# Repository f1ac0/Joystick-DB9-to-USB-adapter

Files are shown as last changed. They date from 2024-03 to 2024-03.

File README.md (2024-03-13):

# Joystick DB9 to USB adapter
Connect an Atari/Amiga joystick or mouse to your PC using USB.

While plugging or powering up the adapter :
- leave all buttons disconnected to use a standard 1-3 buttons joystick or a CD32 pad (not really tested)
- press button 1 to control the PC mouse pointer using the joystick
- press button 2/right mouse button to use an Amiga mouse to control the PC pointer
- press both button 1 and 2/left and right mouse buttons to use an Atari mouse to control the PC pointer

# Disclaimer
This is a hobbyist project, it comes with no warranty and no support.

I publish my work under the CC-BY-NC-SA license.

If you find it useful and want to reward my hard work : I am always looking for Amiga/Atari/Amstrad/Commodore/Sinclair/Thomson... hardware to repair and hack, please contact me.

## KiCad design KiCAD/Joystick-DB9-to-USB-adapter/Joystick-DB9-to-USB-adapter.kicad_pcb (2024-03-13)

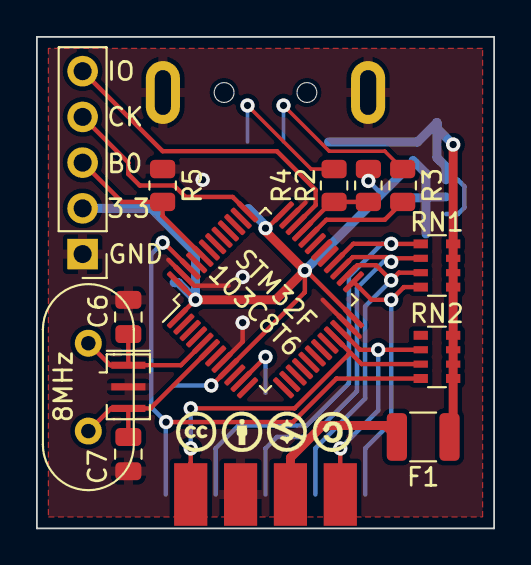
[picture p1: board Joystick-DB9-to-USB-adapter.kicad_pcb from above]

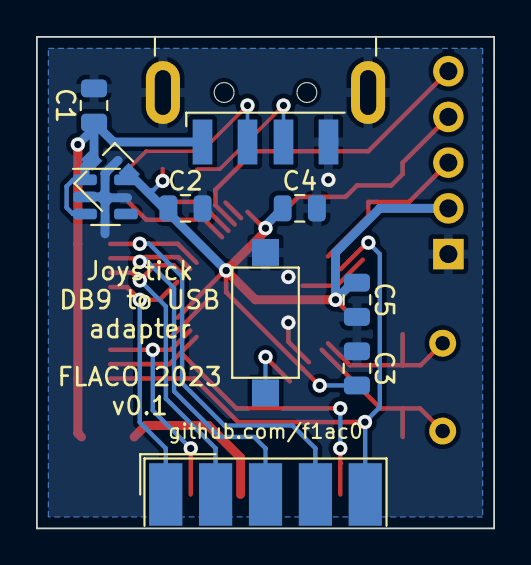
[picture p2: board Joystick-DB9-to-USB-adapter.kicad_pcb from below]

Board: 2 copper layers, 25.4 x 27.3 mm, 24 parts (10 on the bottom side), 21 nets.

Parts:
C1, C2: 1u; C_0805_2012Metric
C3, C4, C5: 100n; C_0805_2012Metric
C6, C7: 22p; C_0805_2012Metric
F1: Polyfuse 0.5A max; R_1210_3225Metric
FID1: License; CC_BY_NC_SA_long_silkscreen_11.4x3.5
J1: DE9_Receptacle; DSUB-9_Male_EdgeMount_P2.77mm
J2: USB_A; USB_A_CNCTech_1001-011-01101_Horizontal
J3: Prog; PinHeader_1x05_P2.54mm_Vertical
R2: 10k; R_0805_2012Metric
R3, R4: 22; R_0805_2012Metric
R5: 100k; R_0805_2012Metric
RN1, RN2: 10k; R_Array_Convex_4x0603
SW1: SEL; SW_SPST_CK_RS282G05A3
U1: STM32F103C8Tx; LQFP-48_7x7mm_P0.5mm
U2: SPX3819M5-L-3-3; SOT-23-5
U3: XC6206PxxxMR; SOT-23
Y1: 8.000; Crystal_HC49-4H_Vertical
Y2: 8MHz; Resonator_SMD_Murata_CSTxExxV-3Pin_3.0x1.1mm

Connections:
5V: F1.1, J1.7
+3.3V: C2.1, C3.1, C4.1, C5.1, J3.2, R2.1, U1.1 (VBAT), U1.9 (VDDA), U1.24 (VDD), U1.36 (VDD), U1.48 (VDD), U2.5 (OUT), U3.2 (VO)
+5V: C1.1, F1.2, J2.1 (VBUS), RN1.5 (R4.2), RN1.6 (R3.2), RN1.7 (R2.2), RN1.8 (R1.2), RN2.5 (R4.2), RN2.6 (R3.2), RN2.7 (R2.2), RN2.8 (R1.2), U2.1 (IN), U2.3 (EN), U3.3 (VI)
/BOOT0: J3.3, R5.1, U1.44 (BOOT0)
/SWCLK: J3.4, U1.37 (PA14)
/SWDIO: J3.5, U1.34 (PA13)
/USB_D+: J2.3 (D+), R4.1
/USB_D-: J2.2 (D-), R3.1
GND: C1.2, C2.2, C3.2, C4.2, C5.2, C6.2, C7.2, J1.8, J2.4 (GND), J2.5 (Shield), J3.1, R5.2, SW1.2, U1.8 (VSSA), U1.23 (VSS), U1.35 (VSS), U1.47 (VSS), U2.2 (GND), U3.1 (GND), Y2.2
J: SW1.1, U1.11 (PA1)
unnamed: R3.2, U1.32 (PA11)
unnamed: R2.2, R4.2, U1.33 (PA12)
unnamed: C6.1, U1.5 (PD0), Y1.1, Y2.1
unnamed: C7.1, U1.6 (PD1), Y1.2, Y2.3
/DOWN: J1.2, RN1.3 (R3.1), U1.26 (PB13)
/F1_CLK: J1.6, RN2.2 (R2.1), U1.22 (PB11)
/F2_DATA: J1.9, RN2.3 (R3.1), U1.21 (PB10)
/F3_LOAD_SHIFT: J1.5, RN2.4 (R4.1), U1.46 (PB9)
/LEFT: J1.3, RN1.2 (R2.1), U1.27 (PB14)
/RIGHT: J1.4, RN1.1 (R1.1), U1.28 (PB15)
/UP: J1.1, RN1.4 (R4.1), U1.25 (PB12)

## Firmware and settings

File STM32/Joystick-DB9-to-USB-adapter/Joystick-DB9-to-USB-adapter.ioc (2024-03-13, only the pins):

Mcu.UserName=STM32F103C8Tx
PA1.GPIO_Label=BUTTON
PA1.Signal=GPIO_Input
PA11.Signal=USB_DM
PA12.Signal=USB_DP
PA13.Signal=SYS_JTMS-SWDIO
PA14.Signal=SYS_JTCK-SWCLK
PB10.GPIO_Label=F2_DATA
PB10.Signal=GPIO_Input
PB11.GPIO_Label=F1_CLK
PB11.Signal=GPIO_Input
PB12.GPIO_Label=UP
PB12.Signal=GPIO_Input
PB13.GPIO_Label=DOWN
PB13.Signal=GPIO_Input
PB14.GPIO_Label=LEFT
PB14.Signal=GPIO_Input
PB15.GPIO_Label=RIGHT
PB15.Signal=GPIO_Input
PB9.GPIO_Label=F3_LOAD_SHIFT
PB9.Signal=GPIO_Input
PD0-OSC_IN.Signal=RCC_OSC_IN
PD1-OSC_OUT.Signal=RCC_OSC_OUT

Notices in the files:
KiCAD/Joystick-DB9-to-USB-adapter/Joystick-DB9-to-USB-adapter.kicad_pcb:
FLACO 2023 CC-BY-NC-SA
